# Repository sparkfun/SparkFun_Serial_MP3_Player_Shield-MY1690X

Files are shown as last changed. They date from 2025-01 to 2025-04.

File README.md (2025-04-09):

SparkFun Serial MP3 Player Shield - MY1690X
========================================

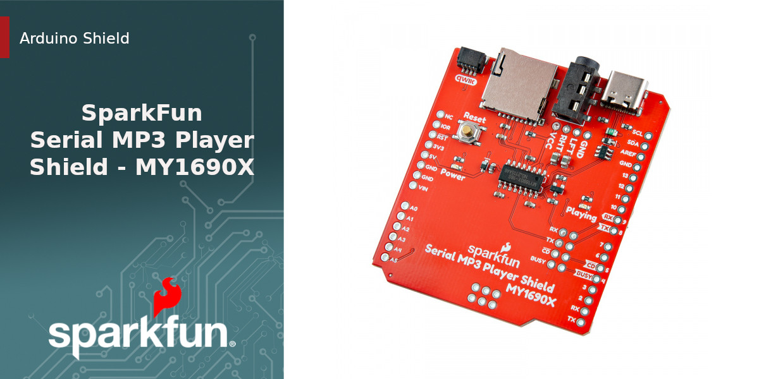
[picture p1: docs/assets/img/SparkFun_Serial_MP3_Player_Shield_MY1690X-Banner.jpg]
SparkFun Serial MP3 Player Shield - MY1690X (https://www.sparkfun.com/sparkfun-serial-mp3-player-shield-my1690x.html)


[*SparkFun Serial MP3 Player Shield - MY1690X (DEV-28021)*](https://www.sparkfun.com/sparkfun-serial-mp3-player-shield-my1690x.html)

The SparkFun Serial MP3 Player Shield - MY1690X is an R3 Arduino shield built around the MY1690X audio decoder IC. The MY1691X supports both .WAV and .MP3 audio files stored on a connected microSD card with up to 32GB capacity and formatted to FAT16 or FAT32. The MY1690X communicates over serial UART so we designed this shield to allow users to control the MY1690X while mounted on a compatible Arduino development board with an R4 footprint. 

Repository Contents
-------------------

* **.github/workflows** - YAML files used for GitHub Actions and GitHub Pages/mkdocs
* **/Hardware** - KiCad design files (.kicad_pcb, .kicad_sch, .kicad_pro)
  * **/Production** - Production panel files (.kicad_pcb)
* **/docs** - Online documentation files
  * **/assets** - Folder containing all the file assets used for product documentation
    * **/board_files** - Copy of design files used for product documentation
    * **/component_documentation** - Datasheets and manuals for hardware components
    * **/img** - Images for product documentation
  * **/github** - Files stating how to contribute and filing issues used for product documentation
  * **/javascript** - Folder containing custom javascript used for product documentation
  * **/stylesheet** - Folder containing CSS files used for product documentation
* **/overrides** - Customization files used for product documentation
  * **/.icons** - Icons used for GitHub used for product documentation
  * **./partials** - Used for product documentation

Documentation
--------------

* **[Arduino Library](https://github.com/sparkfun/SparkFun_MY1690_MP3_Decoder_Arduino_Library/)** - Arduino Library for the SparkFun Serial MP3 Player Shield - MY1690X.
* **[Hookup Guide](https://docs.sparkfun.com/SparkFun_Serial_MP3_Player_Shield-MY1690X)** - Basic hookup guide for the SparkFun Serial MP3 Player Shield - MY1690X.

Product Versions
----------------
* [DEV-28021](https://www.sparkfun.com/sparkfun-serial-mp3-player-shield-my1690x.html) - v1.0

Version History
---------------
* v1.0 - Initial release

License Information
-------------------

This product is _**open source**_!

Please review the LICENSE.md file for license information.

If you have any questions or concerns on licensing, please contact technical support on our [SparkFun forums](https://community.sparkfun.com/c/community/general-chit-chat/37).

Distributed as-is; no warranty is given.

- Your friends at SparkFun.

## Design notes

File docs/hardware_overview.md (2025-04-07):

Let's take a closer look at the SparkFun Serial MP3 Player Shield - MY1690X and the hardware present on the board. The photo below highlights the major components on this shield that we'll cover in more detail in this section:

<center>
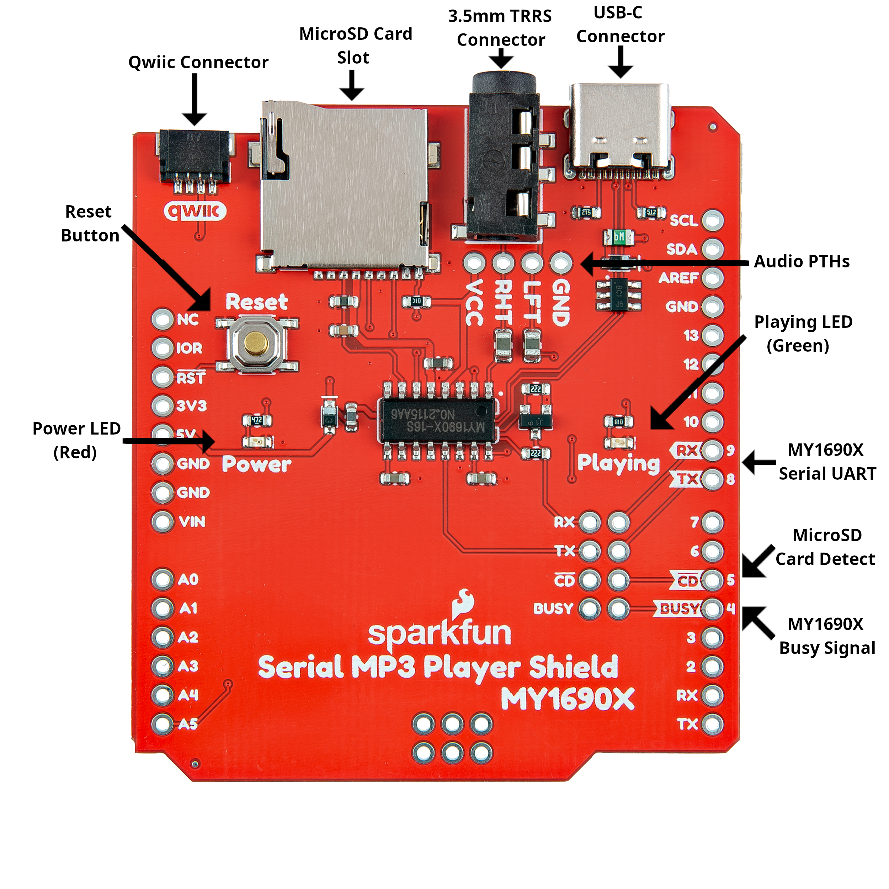
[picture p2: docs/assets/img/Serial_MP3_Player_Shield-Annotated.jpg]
Annotated photo of the MP3 Player Shield

</center>

## MY1690X MP3 Decoder IC

The MY1690X is an MP3 decoder IC that works with both MP3 and WAV audio files stored on a connected &micro;SD card. The MY1690X can function both as a removable USB drive when connected over USB to load, view or edit files on the SD card. The IC operates over a serial-UART interface at 3.3V TTL using a command set to control audio playback (Play, Pause, Next, etc.), volume and equalizer settings and query statuses (SD card contents, track name/length, etc.). It supports audio files with sampling rates between 8 and 48k with bit rates between 8 and 320Kbps.

## Connectors

The Serial MP3 Player Shield has three connectors. A USB-C connector, Qwiic connector and 3.5mm TRRS connector.

### USB-C

The USB-C connector on the shield connects directly to the MY1690X to mount it as a removable USB drive when a microSD card is inserted and the board is plugged into a computer. This allows you to directly add and remove audio files to a connected microSD card. This works great for small audio files but in our testing we found the transfer speed is quite slow and can take several minutes to upload larger audio files. We recommend uploading large files using a USB SD card reader or directly connecting your SD card to your computer.

When connected over USB-C (and with a microSD card plugged in) the MY1690X will stay in USB drive "mode" until a power cycle. The MY1690X does not have a Reset line so either unplug the board or press the RESET button on the shield to cycle power.

### Qwiic

The Qwiic connector on the shield lets you easily add other Qwiic devices to the board. It connects to 3.3V, Ground and both the dedicated SDA/SCL pins as well as A4 (SDA) and A5 (SCL).

### 3.5MM TRRS

The shield routes the audio output from the MY1690X to a 3.5MM TRRS audio connector as well as four 0.1"-spaced through hole pins. This allows you to easily plug in a pair of headphones directly to the shield or solder an alternate audio output. Note, the MY1690X can easily output audio for small headphones but you'll need an external amplifier on the audio output to drive larger speakers.

## MicroSD Card Slot

The shield's microSD card slot works with most standard SD cards that have up to 32GB storage space and formatted to FAT16 or FAT32. The MY1690X requires specific naming of files and folders stored on the card. Read on to the MicroSD Card Setup section of this guide for detailed information on naming conventions.

## Pinout

The Serial MP3 Player Shield matches the R4 footprint and has passthroughs for all of the pins on R4 development boards. The shield connects to the following pins on a connected Arduino dev board:

* D4 - MY1690X Busy Signal
* D5 - MY1690X Card Detect
* D8 - MY1690X TX Signal
* D9 - MY1690X RX Signal
* A4 - Qwiic SDA
* A5 - Qwiic SCL

The shield also has a 2x4 set of PTH pins near the center of the board to allow for routing the serial UART pins (RX/TX), Card Detect (CD) and Busy pins to alternate pins on a connected development board if necessary.

## LEDs

The Serial MP3 Player Shield has two LEDs labeled **PWR** and **BUSY**. The red **PWR** LED indicates whenever the board is powered. The green **BUSY** LED indicates whenever the MY1690X is playing audio.

## Reset Button

The Reset button on the shield is routed to a connected development board's reset pin to be used to reset the development board it's mounted on.

## Solder Jumpers

The shield has seven solder jumpers labeled **MIC**, **BUSY**, **PWR**, **RX**, **TX**, **CD** and **BUSY** (the two BUSY jumpers have different functions). The list below outlines each jumper's label, function, default state and any notes on how they work.

* **MIC** - The MIC jumper connects the Sleeve pin on the TRRS connector to Ground and is CLOSED by default. Open the jumper to disable this pull-down for headphones that have a built-in microphone.
* **BUSY** - The first BUSY jumper completes the Busy LED circuit and is CLOSED by default. Open the jumper to disable the Busy LED.
* **PWR** - The PWR jumper completes the Power LED circuit and is CLOSED by default. Open the jumper to disable the Power LED.
* **RX** - The RX jumper connects the MY1690X's RX pin to D9 and is CLOSED by default. Open the jumper to isolate the MY1690X's RX signal from D9 if you need to route it to another pin.
* **TX** - The TX jumper connects the MY1690X's TX pin to D9 and is CLOSED by default. Open the jumper to isolate the TX signal from D8 if you need to route it to another pin.
* **CD** - The CD jumper connects the MY1690X's Card Detect (CD) to D4 and is CLOSED by default. Open the jumper to disconnect the CD pin from D4 if you need to connect it to another pin.
* **BUSY** - The second BUSY jumper connects the MY1690X's Busy pin to D5 and is CLOSED by default. Open the jumper to disconnect the Busy pin from D5 if you need to connect it to another pin.

## Board Dimensions

The Serial MP3 Player Shield - MY1690X fits the R4 footprint and measures 2.35" x 2.1" (59.69mm x 53.34mm).

<center>
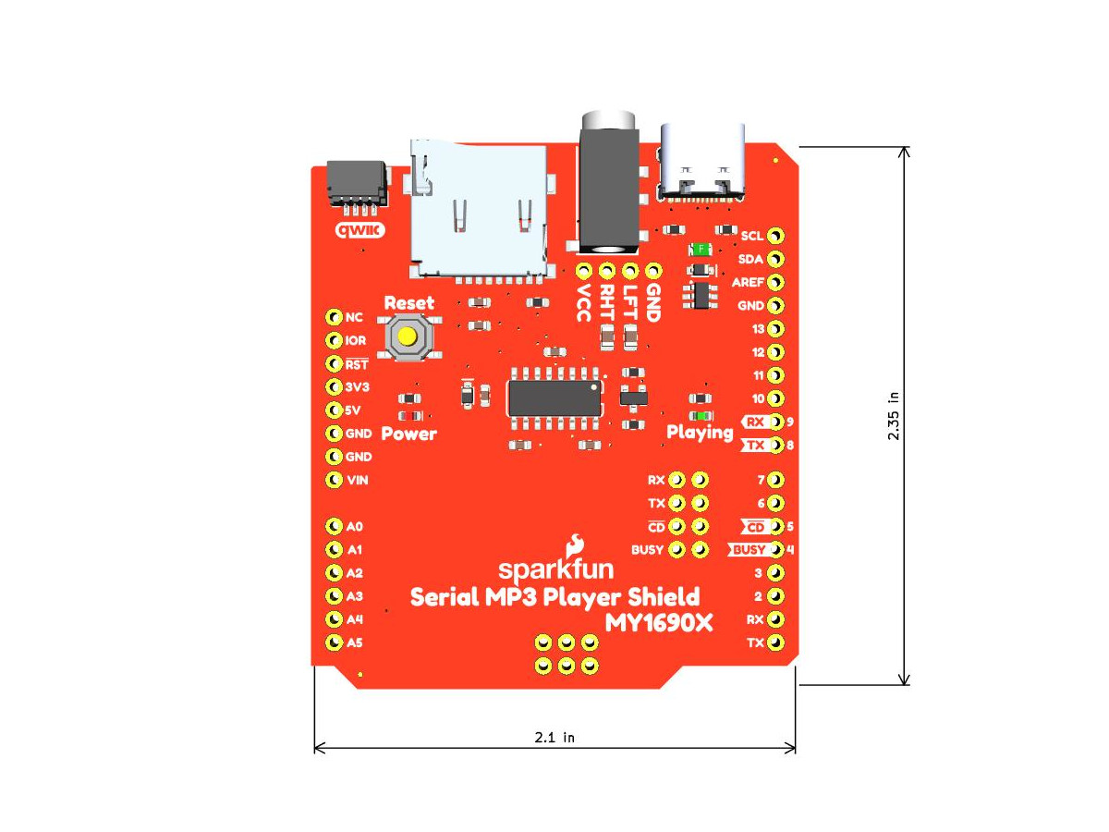
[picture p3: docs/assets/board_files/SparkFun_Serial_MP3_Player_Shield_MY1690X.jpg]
Board Dimensions

</center>

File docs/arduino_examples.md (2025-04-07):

The SparkFun MY1690 MP3 Decoder Arduino library includes three examples to demonstrate how to use the library. Let's take a closer look at these examples.

## Example 1 - Play File

The first example plays the first audio track stored on a connected SD card once through and stops. In Arduino, open the example by navigating to **File** > **Examples** > **SparkFun MY1690X MP3 Decoder Arduino Library** > **Example1_PlayFile**. Select the **Board** and **Port** and click "Upload". Once upload finishes, the code will automatically start by playing the first track stored on the SD card so make sure to have headphones/speakers connected to hear the audio as it does not repeat. You can push the Reset button on the shield to reset the board and start the code over to hear the track play again.

The code does have some serial printouts to help troubleshoot if the code hangs on attempting to initialize the MY1690X or when checking the SD card for audio tracks. If you have any issues with playback, open the [serial monitor](https://docs.arduino.cc/software/ide-v2/tutorials/ide-v2-serial-monitor/) with the baud set to **115200** to view the serial prints from the code.

## Example 2 - Kitchen Sink

The second example demonstrates how to use all of the available commands on the MY1690X to control and manipulate audio tracks through a serial menu. Open the example by navigating to **File** > **Examples** > **SparkFun MY1690X MP3 Decoder Arduino Library** > **Example2_KitchenSink**. Select the **Board** and **Port** and click "Upload". After the code finishes uploading, open the serial monitor with the baud set to **115200** and you should see a menu like the screenshot below:

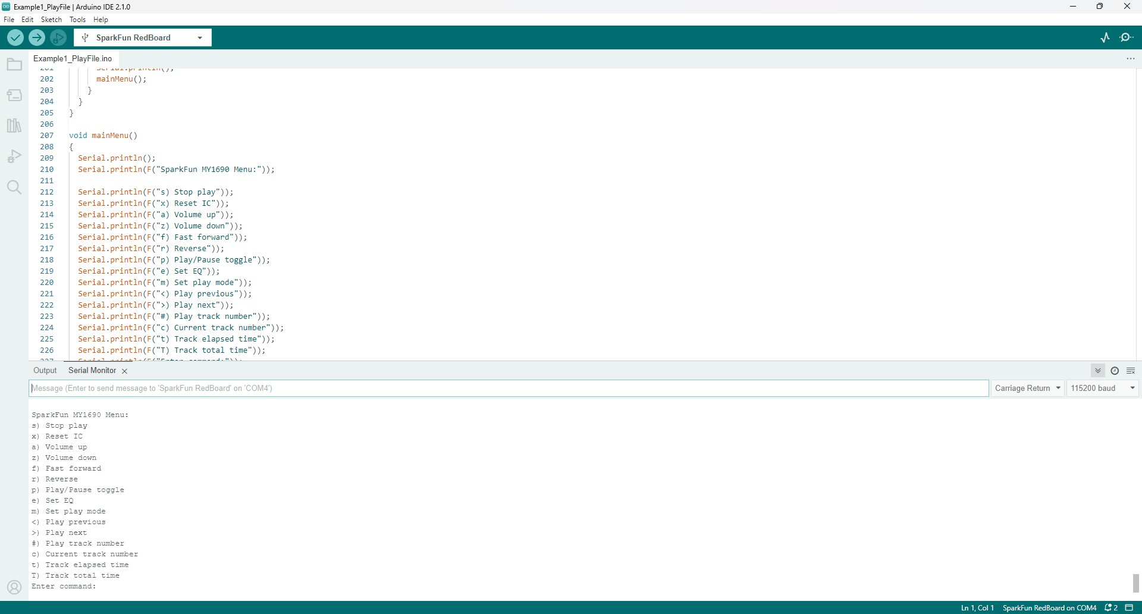
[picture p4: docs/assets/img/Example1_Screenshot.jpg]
Screenshot of example 2 serial menu


The MY1690 Menu has options for all the available playback and settings commands for the MY1690X. Some like "Play" or "Reverse" are straightforward and perform the expected action. The options for setting the equalizer (Set EQ) and play mode (Set Play Mode) cycle through the available options for these settings and print out the matching number. The Equalizer and Play modes are listed below and can be found in the instruction list in section 6.1 of the [MY1690X datasheet](./assets/component_documentation/MY1690X‑16S%20MP3%20Decoder%20IC%20User%20Manual.pdf):

**Equalizer Modes**

* 0 - None
* 1 - Pop
* 2 - Rock
* 3 - Jazz
* 4 - Classic
* 5 - Bass

**Play Modes**

* 0 - Full
* 1 - Folder
* 2 - Single
* 3 - Random
* 4 - No Loop

## Example 3 - Kitchen Sink ESP32

Example 3 - Kitchen Sink ESP32 is nearly identical to Example 2 but is modified to work with ESP32-based development boards like the [SparkFun IoT RedBoard - ESP32](https://www.sparkfun.com/sparkfun-iot-redboard-esp32-development-board.html). Open the example by navigating to **File** > **Examples** > **SparkFun MY1690X MP3 Decoder Arduino Library** > **Example2_KitchenSink**. Select the **Board** (SparkFun IoT RedBoard - ESP32 or other ESP32 dev board) and **Port** and click "Upload". After the code finishes uploading, open the serial monitor with the baud set to **115200** to view the same serial menu as pictured above.

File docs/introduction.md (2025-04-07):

Banner photo for Serial MP3 Player Shield

The SparkFun Serial MP3 Player Shield - MY1690X is an R3 Arduino shield built around the MY1690X audio decoder IC. The MY1691X supports both .WAV and .MP3 audio files stored on a connected microSD card with up to 32GB capacity and formatted to FAT16 or FAT32. The MY1690X communicates over serial UART so we designed this shield to allow users to control the MY1690X while mounted on a compatible Arduino development board with an R4 footprint. 

You'll need the following items to follow along with this tutorial:

* [SparkFun Serial MP3 Player Shield - MY1690X](https://www.sparkfun.com/sparkfun-serial-mp3-player-shield-my1690x.html)
* [SparkFun RedBoard Plus](https://www.sparkfun.com/sparkfun-redboard-plus.html) or other R4 Arduino dev board
* [Arduino Stackable Header Kit](https://www.sparkfun.com/arduino-stackable-header-kit-r3.html) or other header type
* [USB-C Cable](https://www.sparkfun.com/reversible-usb-a-to-c-cable-0-8m.html)

This shield does require soldering to work properly so you'll need a soldering iron and soldering accessories to complete the shield assembly.

## Topics Covered

This document contains three main sections: **Quickstart Guide**, **Hardware** and **Software**. 

The Quickstart Guide assumes a working knowledge of how to assemble and use a shield with a compatible Arduino development board along with the required software to program them for your project's needs. It covers a quick assembly and then jumps right into getting the necessary software packages installed to start uploading code in just a few short minutes.

The Hardware pages cover a hardware overview that provides a detailed overview of the Serial MP3 Player Shield - MY1690X covering all the major components on the board in detail as well as a hardware assembly page which goes over the steps required to assemble and use the shield with a compatible Arudino board.

The Software pages give instructions on installing the SparkFun MY1690 MP3 Decoder Arduino and using the examples included in it.

## Resources and Documentation

You'll find the board design files (KiCad files & schematic), relevant documentation (datasheets, white papers, etc.) and other helpful links in the **Resources**. Lastly, the **Support** section includes a Troubleshooting page that includes any helpful tips specific to this board as well as information on how to receive technical support from SparkFun.

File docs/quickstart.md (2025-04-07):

In this Quick Start guide we'll assemble the SparkFun Serial MP3 Player Shield - MY1690X, mount it to a SparkFun RedBoard Plus and use the SparkFun MY1690X MP3 Decoder Arduino Library to play audio stored on a connected microSD card. 

If you're not familiar with using Arduino shields and development boards or the Arduino IDE, refer to the [Hardware](./hardware_overview.md) & [Software](./arduino_setup.md) sections for a detailed overview of the board along with instructions on assembling the shield, installing and using the SparkFun MY1690X MP3 Decoder Arduino Library.

## Shield Assembly & Mounting

Start by soldering your selected headers to the shield so it can mount on to a compatible R4 development board. We opted for male headers here but you can use stackable headers if you'd like to stack another shield on top of this to add more functionality to your audio project:

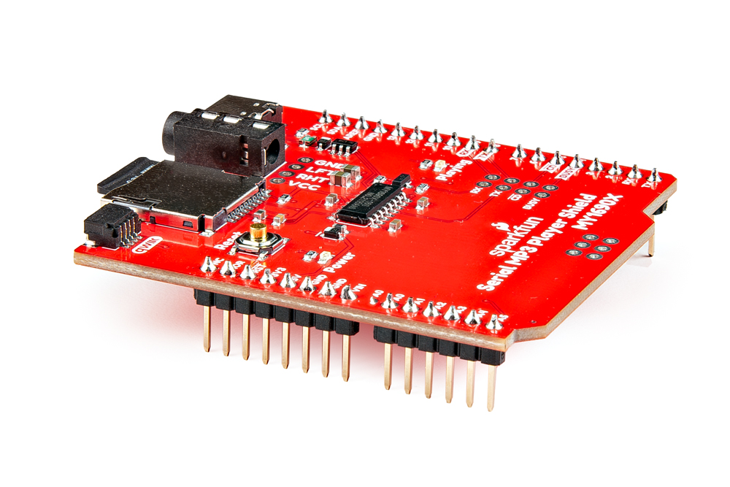
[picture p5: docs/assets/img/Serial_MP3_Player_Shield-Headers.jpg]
Photo showing headers soldered to MP3 Player Shield


After soldering, plug the shield into your development board and connect the development board to your computer with a USB cable:

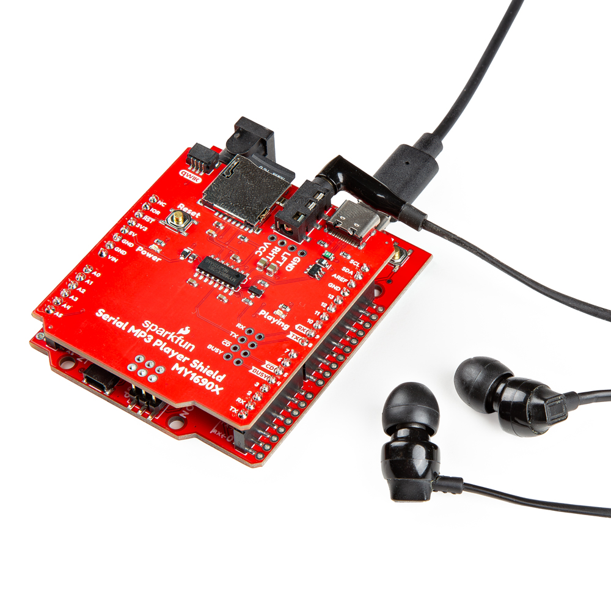
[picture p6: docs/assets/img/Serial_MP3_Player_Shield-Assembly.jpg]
Photo of completed assembly


You'll also want to plug in a pair of headphones to the 3.5mm audio jack on the shield. The MY1690X can drive a pair of headphones on its own but requires an external amplifier to drive larger speakers.

## Prepare SD Card

The MY1690X works with standard SD cards up to 32GB capacity and formatted to either FAT16 or FAT32. Users can upload files to an SD card mounted on the shield by plugging it into a computer over USB-C or can load them directly onto the SD card using a USB Card Reader or the SD card slot on their computer. Files and folders on a connected SD card should match the following naming conventions:

* .MP3/.WAV files in the root directory must begin with a four digit number (eg. 000#) starting at 0001 and can have characters following the numbers
* Folders should begin with a two digit number (eg. 0#) starting at 01 and can have characters following the numbers.
* .MP3/.WAV files stored inside folders must begin with three digits (eg. 00#) starting at 001 and can have characters following the numbers.

Make sure to load the audio tracks onto the SD card and then proceed to the Arduino Example.

## Arduino Example

With the shield soldered and mounted on your Arduino dev board, let's upload Example 2 - Kitchen Sink to the board to start playing and controlling audio. This example will start playing the first track once it's uploaded and also includes a serial menu to access all of the UART commands using simple text commands. Follow the steps below to upload the example.

* Open the [Arduino IDE](https://docs.arduino.cc/software/ide-v2/tutorials/getting-started-ide-v2/).
* Open the [Library Manager](https://docs.arduino.cc/software/ide-v2/tutorials/ide-v2-installing-a-library/) tool, search for "SparkFun MY1690X MP3 Decoder" and install the latest version 
* Open "Example 2 - Kitchen Sink".
* Select your Board (SparkFun RedBoard or other R4 board) and Port and click "Upload".
* After the code compiles and finishes uploading, open the [serial monitor](https://docs.arduino.cc/software/ide-v2/tutorials/ide-v2-serial-monitor/) with the baud set to **115200**.
* The code prints out a menu of available commands to control the MY1690X's playback. Type in the command you'd like to do and hit Enter or click Send.
* Have fun playing around controlling track playback, volume and other features.

Screenshot of example 1 in Arduino

### Code to Note

* Serial Setup
``` c++
#include "SoftwareSerial.h"
SoftwareSerial serialMP3(8, 9); //RX on Arduino connected to TX on MY1690's, TX on Arduino connected to the MY1690's RX pin

//For boards that have multiple hardware serial ports
//HardwareSerial serialMP3(2); //Create serial port on ESP32: TX on 17, RX on 16
```
The code has options for both Software Serial and Hardware Serial depending on your dev board. The code defaults to use pins D8 and D9 for software serial

* MY1690X & Track Checks

```c++
if (myMP3.begin(serialMP3) == false) // Beginning the MP3 player requires a serial port (either hardware or software)
  {
    Serial.println(F("Device not detected. Check wiring. Freezing."));
    while (1);
  }

  int songCount = myMP3.getSongCount();
  if (songCount == 0)
  {
    Serial.println(F("Oh no! No songs found. Make sure the SD card is inserted and there are MP3s on it. Freezing."));
    while (1);
  }
```
On setup, the code checks to detect the MY1690X over serial and also checks to make sure the SD card has audio tracks 

* Get Track Numbers, MY1690 Version and Play First Track
```c++
  Serial.print(F("Number of tracks on SD card: "));
  Serial.println(songCount);

  Serial.print(F("MY1690 Version: "));
  Serial.println(myMP3.getVersion());

  myMP3.play(); //Will play the lowest numbered song in the folder
```

The example will print out the number of tracks detected on the SD card, the MY1690 version and then will play the lowest numbered song on the card. Note, it takes ~30ms for a track to start playing so the code waits 50ms before requesting play status.

* MY1690X Menu Options

This menu shows the available commands to control playback. Type in the matching character in the serial monitor and hit Enter to send it. The Set EQ and Set play mode commands cycle through the available equalizer and play mode options. Refer to the Arduino Examples section of this guide or section 6.1 of the [datasheet](./assets/component_documentation/MY1690X‑16S%20MP3%20Decoder%20IC%20User%20Manual.pdf) for more information.

```c++
void mainMenu()
{
  Serial.println();
  Serial.println(F("SparkFun MY1690 Menu:"));

  Serial.println(F("s) Stop play"));
  Serial.println(F("x) Reset IC"));
  Serial.println(F("a) Volume up"));
  Serial.println(F("z) Volume down"));
  Serial.println(F("f) Fast forward"));
  Serial.println(F("r) Reverse"));
  Serial.println(F("p) Play/Pause toggle"));
  Serial.println(F("e) Set EQ"));
  Serial.println(F("m) Set play mode"));
  Serial.println(F("<) Play previous"));
  Serial.println(F(">) Play next"));
  Serial.println(F("#) Play track number"));
  Serial.println(F("c) Current track number"));
  Serial.println(F("t) Track elapsed time"));
  Serial.println(F("T) Track total time"));
  Serial.println(F("Enter command:"));
}
```

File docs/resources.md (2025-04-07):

Refer to the resources below for more information on the SparkFun Serial MP3 Player Shield - MY1690X.

* [Schematic](./assets/board_files/SparkFun_Serial_MP3_Player_Shield_MY1690X.pdf)
* [KiCad Files](./assets/board_files/SparkFun_Serial_MP3_Player_Shield_MY1690X.zip)
* [Board Dimensions](./assets/board_files/SparkFun_Serial_MP3_Player_Shield_MY1690X.jpg)
* [MY1690X Datasheet](./assets/component_documentation/MY1690X‑16S%20MP3%20Decoder%20IC%20User%20Manual.pdf)
* [SparkFun MP3 Decoder Arduino Library](https://github.com/sparkfun/SparkFun_MY1690_MP3_Decoder_Arduino_Library)
* [GitHub Repository](https://github.com/sparkfun/SparkFun_Serial_MP3_Player_Shield-MY1690X)

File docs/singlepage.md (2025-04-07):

---
hide:
  - navigation
  - toc
icon: fontawesome/solid/scroll
---

# Introduction
--8<-- "./docs/introduction.md"

# Quickstart Guide
--8<-- "./docs/quickstart.md"

# Hardware Overview
--8<-- "./docs/hardware_overview.md"

# Hardware Hookup
--8<-- "./docs/hardware_assembly.md"

# MicroSD Card Setup
--8<-- "./docs/microsd.md

# Setting Up Arduino
--8<-- "./docs/arduino_setup.md"

# Arduino Examples
--8<-- "./docs/arduino_examples.md"

# Troubleshooting
--8<-- "./docs/troubleshooting.md"

# Resources
--8<-- "./docs/resources.md"

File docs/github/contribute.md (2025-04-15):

# Contribute: Make an Augmentation!
Spot an improvement opportunity? Feel free to contribute to our open-source design and documentation. 

## :material-file-document-multiple:&nbsp;Improve our Documentation
All of this documentation can be modified by you! Please help us make it better.

* These pages are contained in the [`docs` folder](https://github.com/sparkfun/SparkFun_Serial_MP3_Player_Shield-MY1690X/tree/main/docs) of the [SparkFun Serial MP3 Player Shield - MY1690X repository](https://github.com/sparkfun/SparkFun_Serial_MP3_Player_Shield-MY1690X).

<!-- ### :material-source-pull:&nbsp;Submit a Correction -->
### Submit a Correction

1. With a GitHub account, [fork this repository](https://github.com/sparkfun/SparkFun_Serial_MP3_Player_Shield-MY1690X/fork).
2. Add your corrections or improvements to the markdown file.
3. File a pull request with your changes, and enjoy making the ~~words~~ ~~worlds~~ world a better place.
	* Once received, the documentation specialist will automatically be notified.
	* We will review your suggested improvements to make sure they are correct and fit within our documentation standards.

## :material-cog:&nbsp;Improve our Hardware Design
All of our designs are open-source! Please help us make it better.

* Our board design files are contained in the [`Hardware` folder](https://github.com/sparkfun/SparkFun_Serial_MP3_Player_Shield-MY1690X/tree/main/Hardware) of the [SparkFun Serial MP3 Player Shield - MY1690X repository](https://github.com/sparkfun/SparkFun_Serial_MP3_Player_Shield-MY1690X).

<!-- ### :material-source-pull:&nbsp;Submit a Design Enhancement -->
### Submit a Design Enhancement

1. With a GitHub account, [fork this repository](https://github.com/sparkfun/SparkFun_Serial_MP3_Player_Shield-MY1690X/fork).
2. Add your design augmentation(s)
3. File a pull request with your changes, and enjoy making the ~~words~~ ~~worlds~~ world a better place.
	1. Once received, the engineer in charge of the original design will automatically be notified.
	2. We will review your suggested improvement(s) to verify that they are within our board design standards and meet our product design requirements.
	3. If approved, we will flag these changes for our next board revision. Congrats! 🍻

		!!! info
			Even if your suggestion is accepted, these changes may not be immediately available for purchase. We may have to cycle through our current product inventory first.

## Contributors&nbsp;:clap:
Let's provide some recognition to the contributors for this project!

GitHub Contributors Image
<br>


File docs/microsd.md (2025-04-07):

The MY1690X works with standard microSD cards up to 32GB capacity and formatted to either FAT16 or FAT32.

## Format &micro;SD Card

If you're using a brand new SD card, you may not need to format it though it may come with pre-installed files that could cause performance issues. The Quick Format option in Windows is the usually the simplest method to properly format the &micro;SD card. Otherwise there are many free software options for formatting SD cards available online.

## Upload Audio Files

The MY1690X supports both .MP3 and .WAV audio files and acts as a removable USB drive while plugged in over USB-C to directly add audio files to a connected &micro;SD card. In our testing, we found the MY1690X transfer speed is somewhat limited and can take several minutes to upload larger files. If you're moving a large number or large files to use on the Serial MP3 Shield you may want to use a USB SD card reader or plug your SD card into the matching slot on your computer. 

### File & Folder Naming

The MY1690X requires specific naming conventions for files and folders stored on the SD card. Audio files stored in the root directory must begin with a four digit number (000#) starting at 0001 and can have characters following the numbers. Folders should be named with two digits at the start (0#) and then can have descriptive characters following the numbers. Files stored in these folders must be named starting with three digits (00#) and can have characters after the numbers. Refer to section 6.3 in the [datasheet](./assets/component_documentation/MY1690X‑16S%20MP3%20Decoder%20IC%20User%20Manual.pdf) for more information on naming requirements.

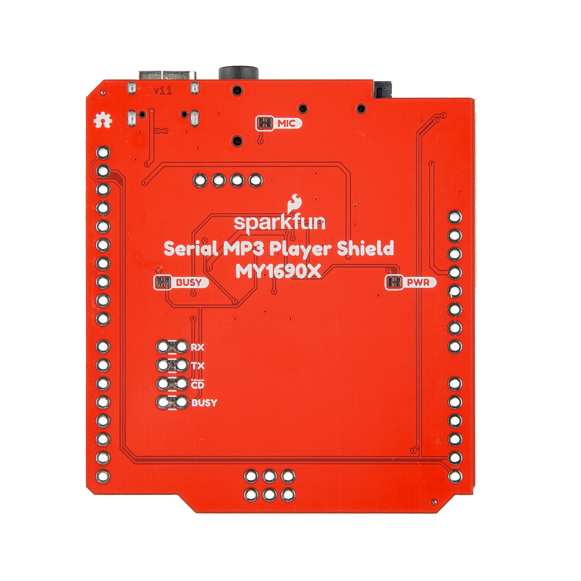
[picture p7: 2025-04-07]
docs/assets/img/28021-Serial-MP3-Player-Shield-Back-high-res.jpg

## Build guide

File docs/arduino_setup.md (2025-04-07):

!!! arduino
    This example assumes you are using the latest version of the Arduino IDE on your desktop. If this is your first time using Arduino IDE, library, or board add-on, please review the following tutorials.

    - [Installing the Arduino IDE](https://learn.sparkfun.com/tutorials/installing-arduino-ide)
    - [Installing an Arduino Library](https://learn.sparkfun.com/tutorials/installing-an-arduino-library)
    - [Installing Board Definitions in the Arduino IDE](https://learn.sparkfun.com/tutorials/installing-board-definitions-in-the-arduino-ide)

## Installing the SparkFun MY1690X MP3 Decoder Arduino Library

The SparkFun MY1690X MP3 Decoder Arduino Library parses the MY1690X's full command set into a user-friendly menu controlled using a serial terminal. Install the library using the Arduino Library Manager tool by searching for "SparkFun MY1690X" and install the latest version. If you'd prefer to manually install the library, you can download it from the [GitHub Repository](https://github.com/sparkfun/SparkFun_MY1690_MP3_Decoder_Arduino_Library) or you can download a ZIP of the repository [here](https://github.com/sparkfun/SparkFun_MY1690_MP3_Decoder_Arduino_Library/archive/refs/heads/main.zip).

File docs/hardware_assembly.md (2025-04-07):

??? note "New to soldering?"
	If you have never soldered before or need a quick refresher, check out our [How to Solder: Through-Hole Soldering](https://learn.sparkfun.com/tutorials/how-to-solder-through-hole-soldering) guide.
	<p align="center">
		<a href="https://learn.sparkfun.com/tutorials/5">
		Tutorial's thumbnail<br>
        How to Solder: Through-Hole Soldering</a>
	</p>

Start by soldering your selected headers to the shield so it can mount on to a compatible R4 development board. We opted for male headers here but you can use stackable headers if you'd like to stack another shield on top of this to add more functionality to your audio project:

Photo showing headers soldered to MP3 Player Shield

After soldering, plug the shield into your development board, insert your microSD card and connect the development board to your computer with a USB cable:

Photo of completed assembly

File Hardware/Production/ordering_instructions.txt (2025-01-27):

Ordering Instructions:
Panel dimensions: 120.80 x 203.85 mm.
Solder Mask: Red
Silkscreen Color: White
Layers: 2
Finish: Lead-free HASL
Thickness: 1.6mm
Outer Copper Weight: 1oz
Minimum track width: 0.15mm (6.00mil)
Minimum via drill: 0.30mm (11.81mil)

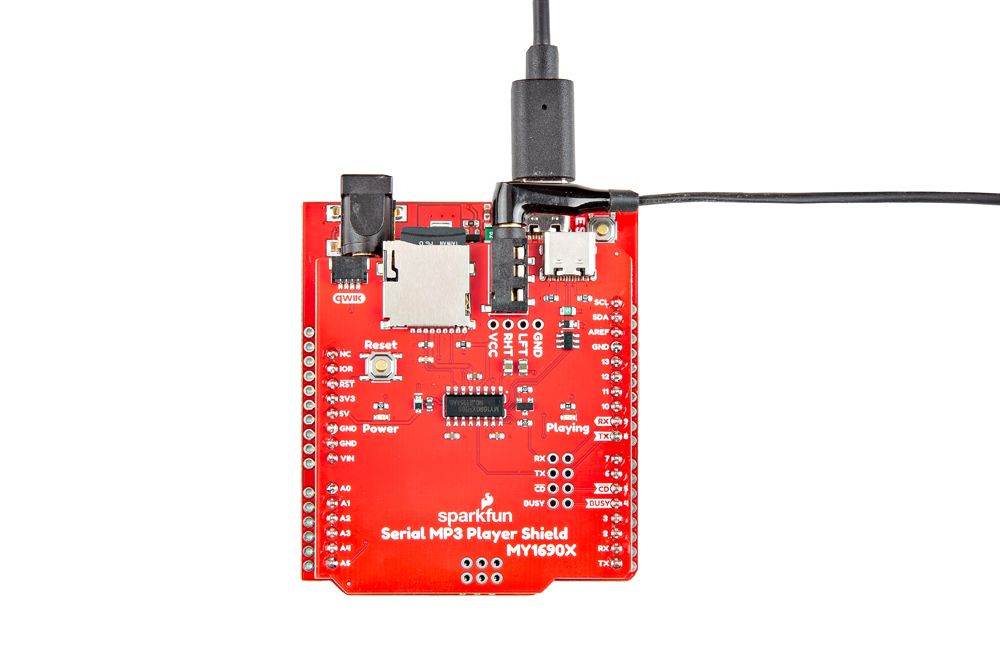
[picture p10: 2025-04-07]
docs/assets/img/Serial_MP3_Player_Shield-Assembly_Top.jpg

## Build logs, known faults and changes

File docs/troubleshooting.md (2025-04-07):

## Audio Track Naming

One of the most common issues we expect you to run into will revolve around track naming outlined in the MicroSD Card Setup section of this guide and section 6.3 of the [datasheet](./assets/component_documentation/MY1690X‑16S%20MP3%20Decoder%20IC%20User%20Manual.pdf).Remember that tracks and folders must start at 0001 (Track in root directory), 001 (Track in folder) and 01 (Folder). Any tracks and folders not explicitly following the naming convention will be ignored by the MY1690X.

## General Troubleshooting Help

!!! note
    <span class="glyphicon glyphicon-question-sign" aria-hidden="true"></span>
        <strong> Not working as expected and need help? </strong> <br /><br />

    If you need technical assistance and more information on a product that is not working as you expected, we recommend heading on over to the <a href="https://www.sparkfun.com/technical_assistance">SparkFun Technical Assistance</a> page for some initial troubleshooting. <br /><br />

    <div style="text-align: center"><a href="https://www.sparkfun.com/technical_assistance" target="sfe_technical_assistance" class="md-button">SparkFun Technical Assistance Page</a></div>

    If you don't find what you need there, the <a href="https://community.sparkfun.com/">SparkFun Forums</a> are a great place to find and ask for help. If this is your first visit, you'll need to create a forum account to search product forums and post questions.<br /><br />

    <div style="text-align: center"><a href="https://community.sparkfun.com/" class="md-button md-button--primary">Log Into SparkFun Forums</a></div>

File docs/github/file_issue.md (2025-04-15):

# Did we make a mistake?

Spot something wrong? Please let us know. 

## Discrepancies in the Documentation

All of our documentation can be modified by you! Please help us make it better.

* The documentation files for these pages are contained in the [`docs` folder](https://github.com/sparkfun/SparkFun_Serial_MP3_Player_Shield-MY1690X/tree/main/docs) of the [SparkFun Serial MP3 Player Shield - MY1690X repository](https://github.com/sparkfun/SparkFun_Serial_MP3_Player_Shield-MY1690X).

### 🔍 Spot something wrong?

If a section of the documentation is incorrect, please [open an issue](https://github.com/sparkfun/SparkFun_Serial_MP3_Player_Shield-MY1690X/issues) and let us know.

### Do you have a suggested correction?

1. With a GitHub account, [fork this repository](https://github.com/sparkfun/SparkFun_Serial_MP3_Player_Shield-MY1690X/fork).
2. Add your correction(s) or improvement(s) to the markdown file(s)
3. File a pull request with your changes, and enjoy making the ~~words~~ ~~worlds~~ world a better place.
	* Once received, the documentation specialist will automatically be notified.
	* We will review your suggested improvement(s) to make sure they are correct and fit within our documentation standards.

## Problems in the Hardware Design

All of our designs are open-source! Please help us make it better.

* Our board design files are contained in the [`Hardware` folder](https://github.com/sparkfun/SparkFun_Serial_MP3_Player_Shield-MY1690X/tree/main/Hardware) of the [SparkFun Serial MP3 Player Shield - MY1690X repository](https://github.com/sparkfun/SparkFun_Serial_MP3_Player_Shield-MY1690X).

### Does something not make sense? 🤔

If part of the design is confusing, please [open an issue](https://github.com/sparkfun/SparkFun_Serial_MP3_Player_Shield-MY1690X/issues) and let us know.

### Did we forget to include an important function of the board? 🤦

If part of the board's functionality is missing, please [open an issue](https://github.com/sparkfun/SparkFun_Serial_MP3_Player_Shield-MY1690X/issues) and file a feature request.

!!! tip "Design Considerations"
	Please keep in mind that we may intentionally exclude certain functions of the board to meet our product design requirements.
	
	* *For example, our Qwiic Micro boards are intended to fit on a small board layout and only use I<sup>2</sup>C communication; therefore, we may not have the SPI and interrupt pins available for users.*

### Do you wish to contribute directly to improving the board design?

1. With a GitHub account, [fork this repository](https://github.com/sparkfun/SparkFun_Serial_MP3_Player_Shield-MY1690X/fork).
2. Add your design augmentation(s)
3. File a pull request with your changes, and enjoy making the ~~words~~ ~~worlds~~ world a better place.
	1. Once received, the engineer in charge of the original design will automatically be notified.
	2. We will review your suggested improvement(s) to verify that they are within our board design standards and meet our product design requirements.
	3. If approved, we will flag these changes for our next board revision. Congrats! 🍻

		!!! info
			Even if your suggestion is accepted, these changes may not be immediately available for purchase. We may have to cycle through our current product inventory first.

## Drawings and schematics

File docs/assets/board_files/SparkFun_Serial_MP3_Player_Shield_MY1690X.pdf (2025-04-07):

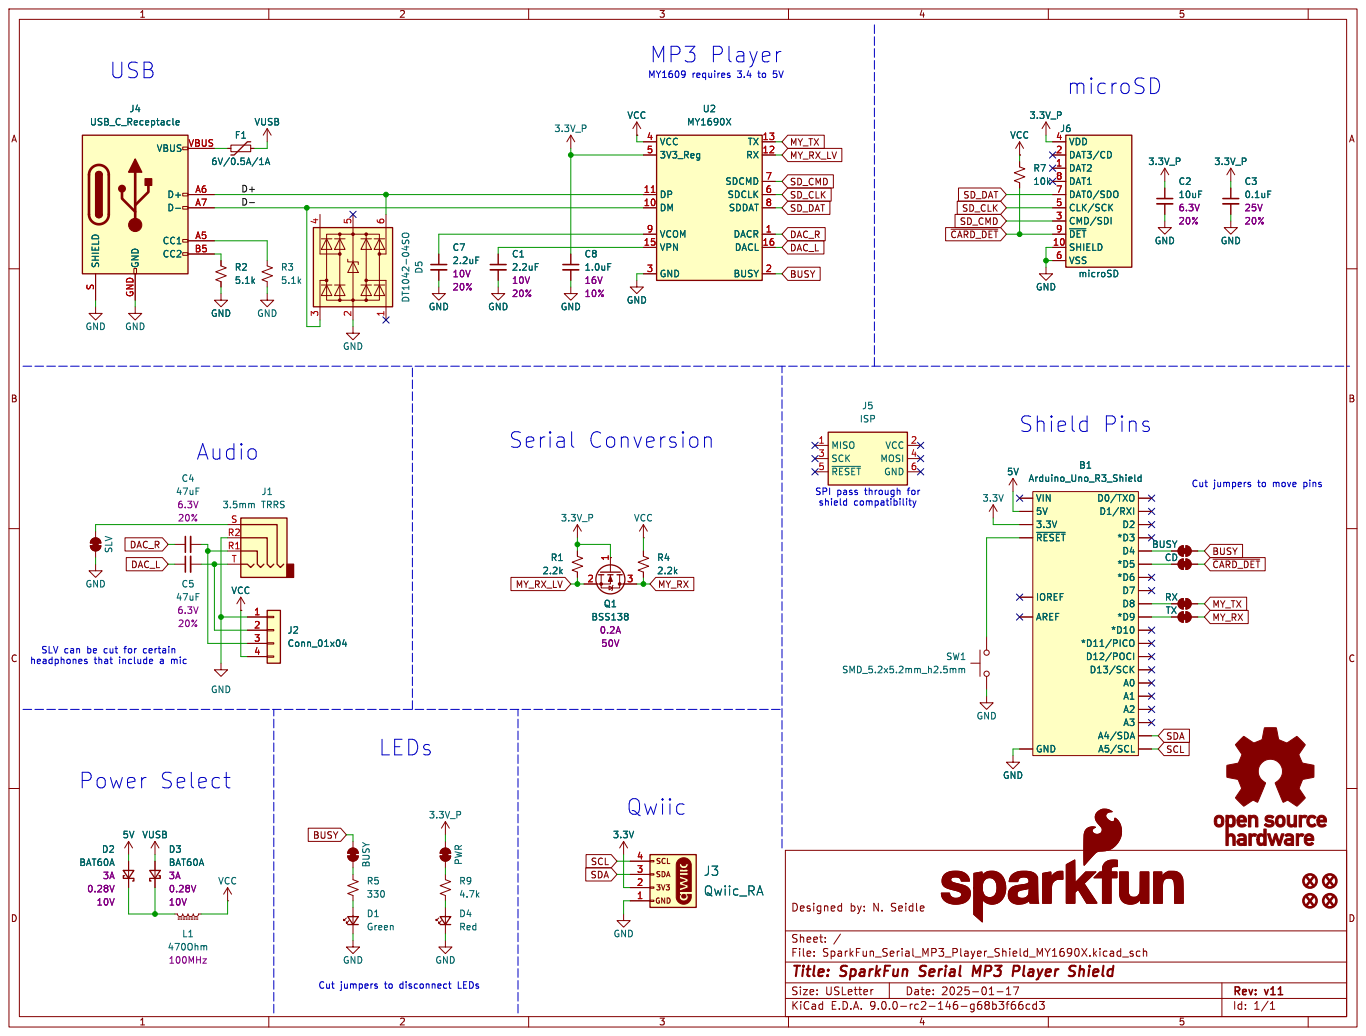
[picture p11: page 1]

VDD 4 DAT3/CD 2 DAT2 1 DAT1 8 DAT0/SDO 7 CLK/SCK 5 CMD/SDI 3 ~{DET} 9 SHIELD 10 VSS 6 VCC

SLV can be cut for certain

Id: 1/1 Title: SparkFun Serial MP3 Player Shield

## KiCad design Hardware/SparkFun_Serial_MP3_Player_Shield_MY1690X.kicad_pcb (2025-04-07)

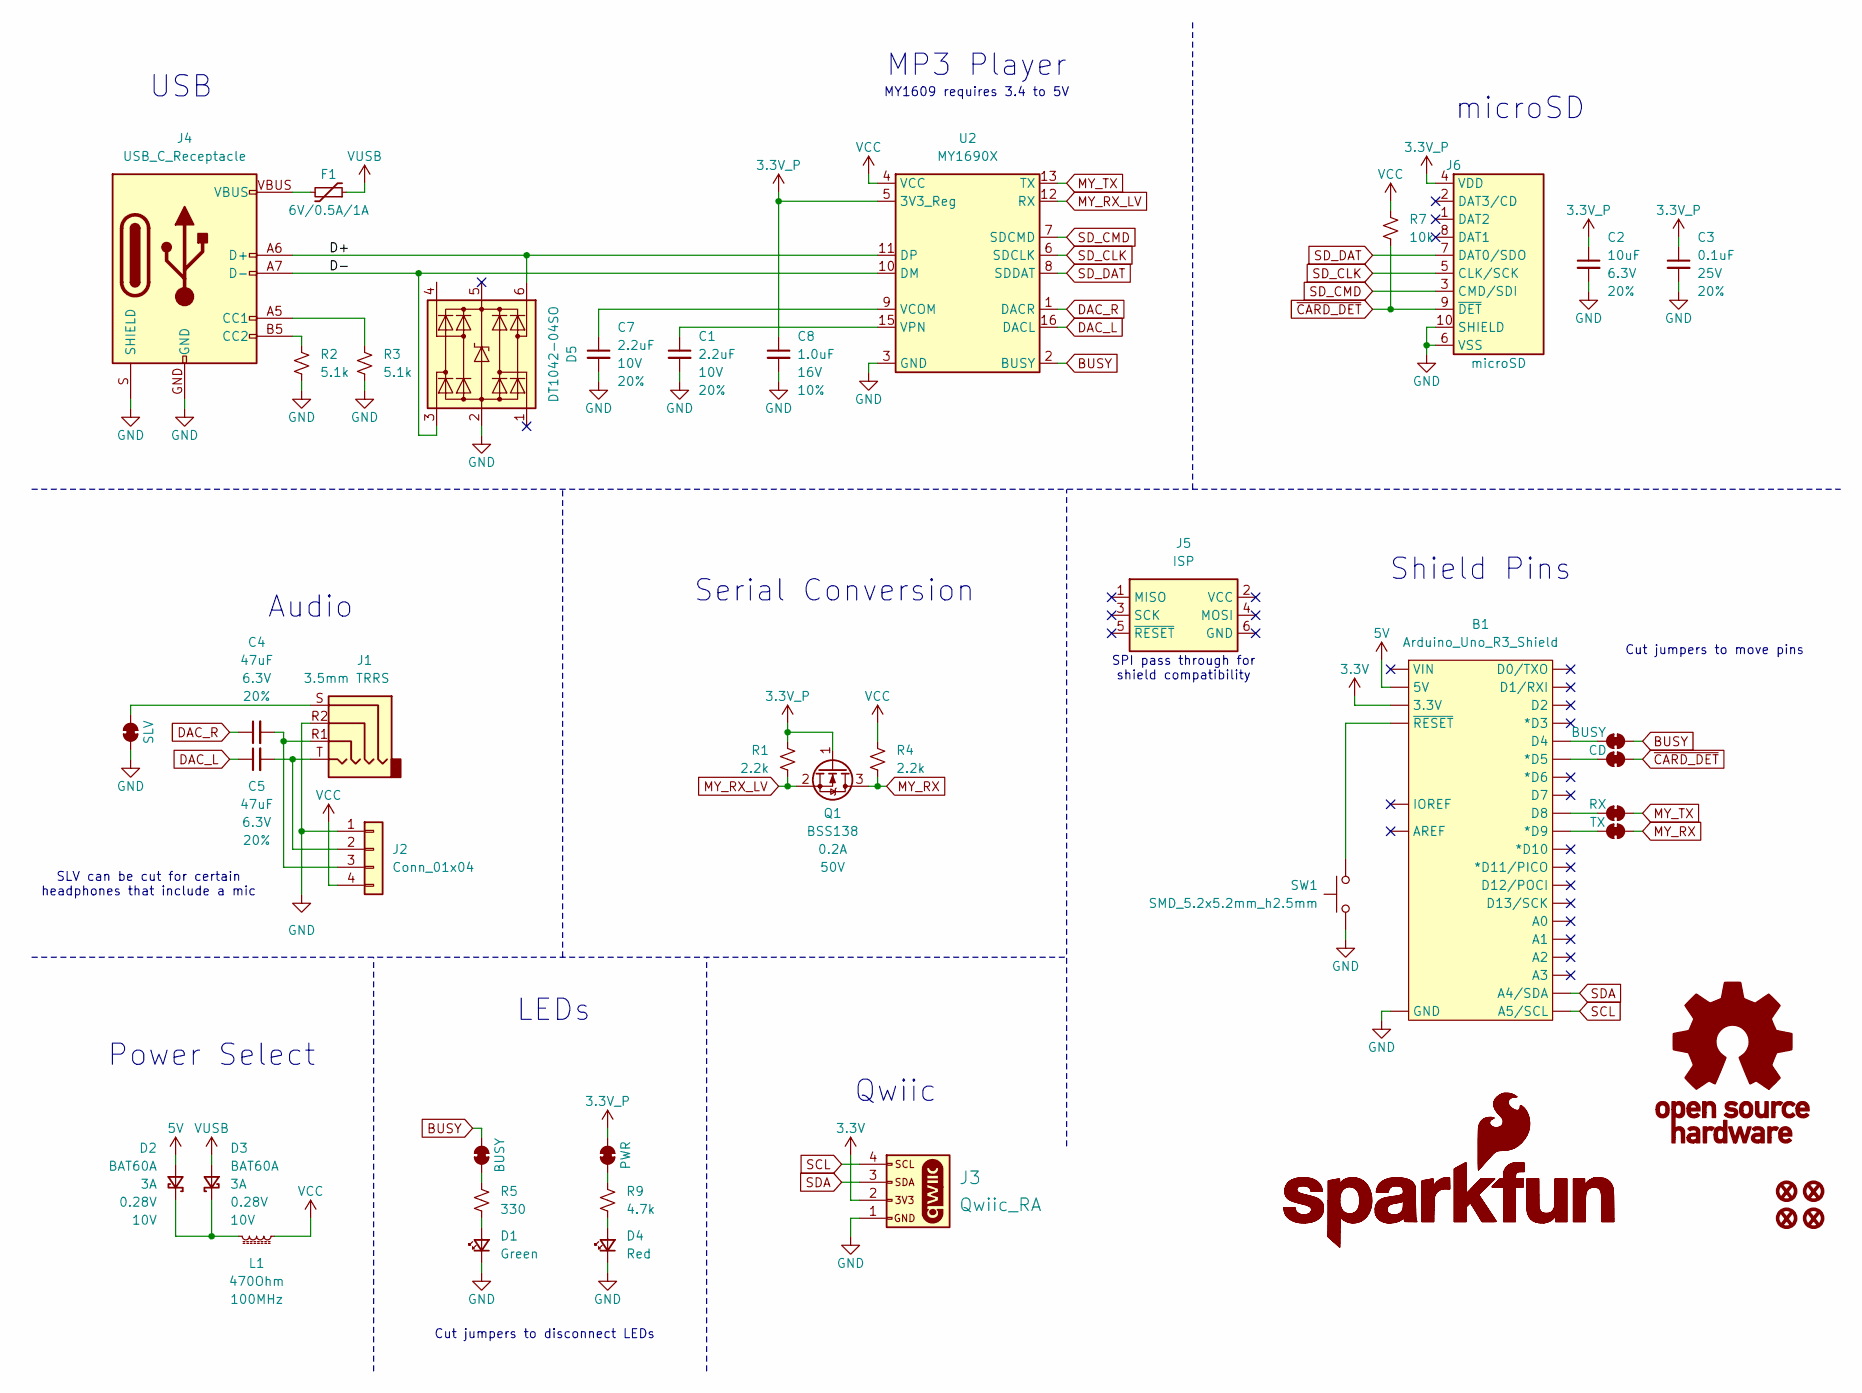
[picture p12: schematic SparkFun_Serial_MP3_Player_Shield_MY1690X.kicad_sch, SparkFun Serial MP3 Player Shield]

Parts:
B1: Arduino_Uno_R3_Shield; Uno_R3_Shield_NoLabels
C1, C7: 2.2uF; C_0603_1608Metric; Voltage 10V; Tolerance 20%
C2: 10uF; C_0603_1608Metric; Voltage 6.3V; Tolerance 20%
C3: 0.1uF; C_0603_1608Metric; Voltage 25V; Tolerance 20%
C4, C5: 47uF; C_0805_2012Metric; Voltage 6.3V; Tolerance 20%
C8: 1.0uF; C_0603_1608Metric; Voltage 16V; Tolerance 10%
D1: Green; LED_0603_1608Metric_Green
D2, D3: BAT60A; SOD-323
D4: Red; LED_0603_1608Metric_Red
D5: DT1042-04SO; SOT23-6
F1: 6V/0.5A/1A; 0805
FID1, FID2, FID3, FID4: Fiducial_0.5mm; Fiducial_0.5mm_Mask1mm
G1: OSHW_Logo; Creative_Commons_License
G3: SparkFun_Logo
G5: SparkFun_Logo; SparkFun_Logo_8mm
J1: 3.5mm TRRS; Audio_Jack_3.5mm_TRRS_SMD_RA
J2: Conn_01x04; 1x04
J3: Qwiic_RA; JST_SMD_1.0mm-4_Black
J4: USB_C_Receptacle; USB-C_16
J5: ISP; 2x03_NoSilk
J6: microSD; microSD_External_Pin
JP1: BUSY; Jumper_2_NC_Trace
JP2: PWR; Jumper_2_NC_Trace
JP3: CD; Jumper_2_PTH_SMD_Combo-NC
JP4: BUSY; Jumper_2_PTH_SMD_Combo-NC
JP5: RX; Jumper_2_PTH_SMD_Combo-NC
JP6: TX; Jumper_2_PTH_SMD_Combo-NC
JP7: SLV; Jumper_2_NC_Trace
L1: 470Ohm; C_0603_1608Metric
Q1: BSS138; SOT23-3
R1, R4: 2.2k; R_0603_1608Metric
R2, R3: 5.1k; R_0603_1608Metric
R5: 330; R_0603_1608Metric
R7: 10k; R_0603_1608Metric
R9: 4.7k; R_0603_1608Metric
SW1: SMD_5.2x5.2mm_h2.5mm; Push_SMD_5.2x5.2mm_h2.5mm
U2: MY1690X; SO-16

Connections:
3.3V: B1.3.3V, J3.2
3.3V_P: C2.1, C3.1, C8.1, J6.4 (VDD), JP2.2 (B), Q1.1 (G), R1.2, U2.5 (3V3_Reg)
5V: B1.5V, D2.2 (A)
/D+: D5.6 (I/O4), J4.A6 (D+), J4.B6 (D+), U2.11 (DP)
/D-: D5.3 (I/O2), J4.A7 (D-), J4.B7 (D-), U2.10 (DM)
BUSY: JP1.2 (B), JP4.2 (B), U2.2 (BUSY)
DAC_L: C5.1, U2.16 (DACL)
DAC_R: C4.1, U2.1 (DACR)
GND: B1.GND, C1.2, C2.2, C3.2, C7.2, C8.2, D1.1 (K), D4.1 (K), D5.2 (GND), J1.R2, J2.1, J3.1, J4.GND, J4.S (SHIELD), J6.6 (VSS), J6.10 (SHIELD), JP7.1 (A), R2.2, R3.1, SW1.1, U2.3 (GND), U2.14 (GND)
MY_RX: JP6.2 (B), Q1.3 (D), R4.1
MY_RX_LV: Q1.2 (S), R1.1, U2.12 (RX)
MY_TX: JP5.2 (B), U2.13 (TX)
unnamed: B1.D5 (*D5), JP3.1 (A)
unnamed: B1.D9 (*D9), JP6.1 (A)
unnamed: B1.~{RESET}, SW1.2
unnamed: D1.2 (A), R5.1
unnamed: D2.1 (K), D3.1 (K), L1.2
unnamed: D4.2 (A), R9.1
unnamed: F1.2, J4.VBUS
unnamed: C5.2, J1.T, J2.2
unnamed: C4.2, J1.R1, J2.3
unnamed: J4.A5 (CC1), R3.2
unnamed: J4.B5 (CC2), R2.1
unnamed: JP1.1 (A), R5.2
unnamed: JP2.1 (A), R9.2
unnamed: B1.D4, JP4.1 (A)
unnamed: B1.D8, JP5.1 (A)
unnamed: J1.S, JP7.2 (B)
unnamed: C7.1, U2.9 (VCOM)
unnamed: C1.1, U2.15 (VPN)
SCL: B1.A5/SCL, J3.4
SDA: B1.A4/SDA, J3.3
SD_CLK: J6.5 (CLK/SCK), U2.6 (SDCLK)
SD_CMD: J6.3 (CMD/SDI), U2.7 (SDCMD)
SD_DAT: J6.7 (DAT0/SDO), U2.8 (SDDAT)
VCC: J2.4, L1.1, R4.2, R7.2, U2.4 (VCC)
VUSB: D3.2 (A), F1.1
~CARD_DET: J6.9 (~DET), JP3.2 (B), R7.1

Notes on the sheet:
Cut jumpers to disconnect LEDs
MY1609 requires 3.4 to 5V
Serial Conversion
Cut jumpers to move pins
Audio
USB
microSD
SPI pass through for shield compatibility
SLV can be cut for certain headphones that include a mic
MP3 Player
Qwiic
Power Select
Shield Pins
LEDs

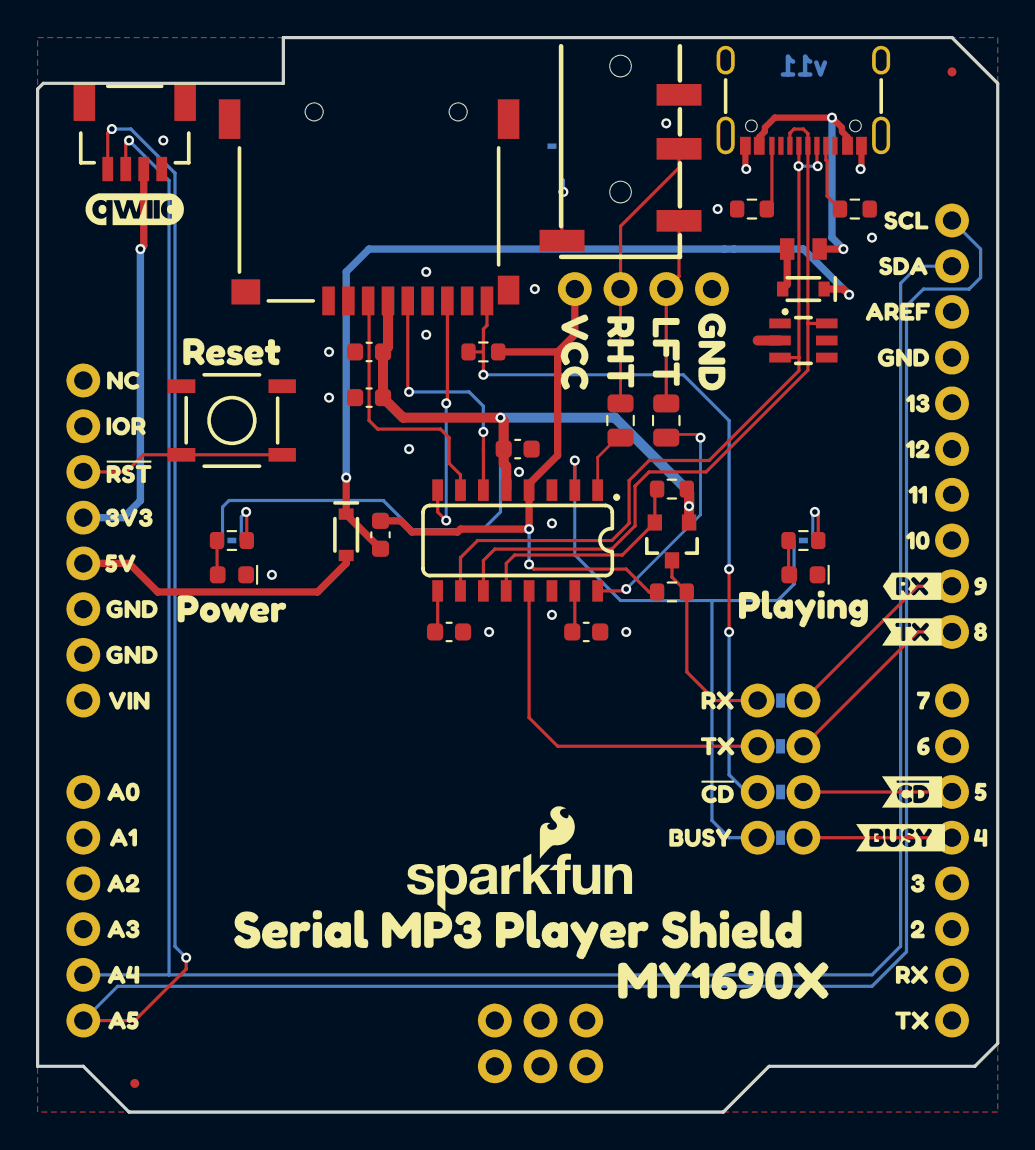
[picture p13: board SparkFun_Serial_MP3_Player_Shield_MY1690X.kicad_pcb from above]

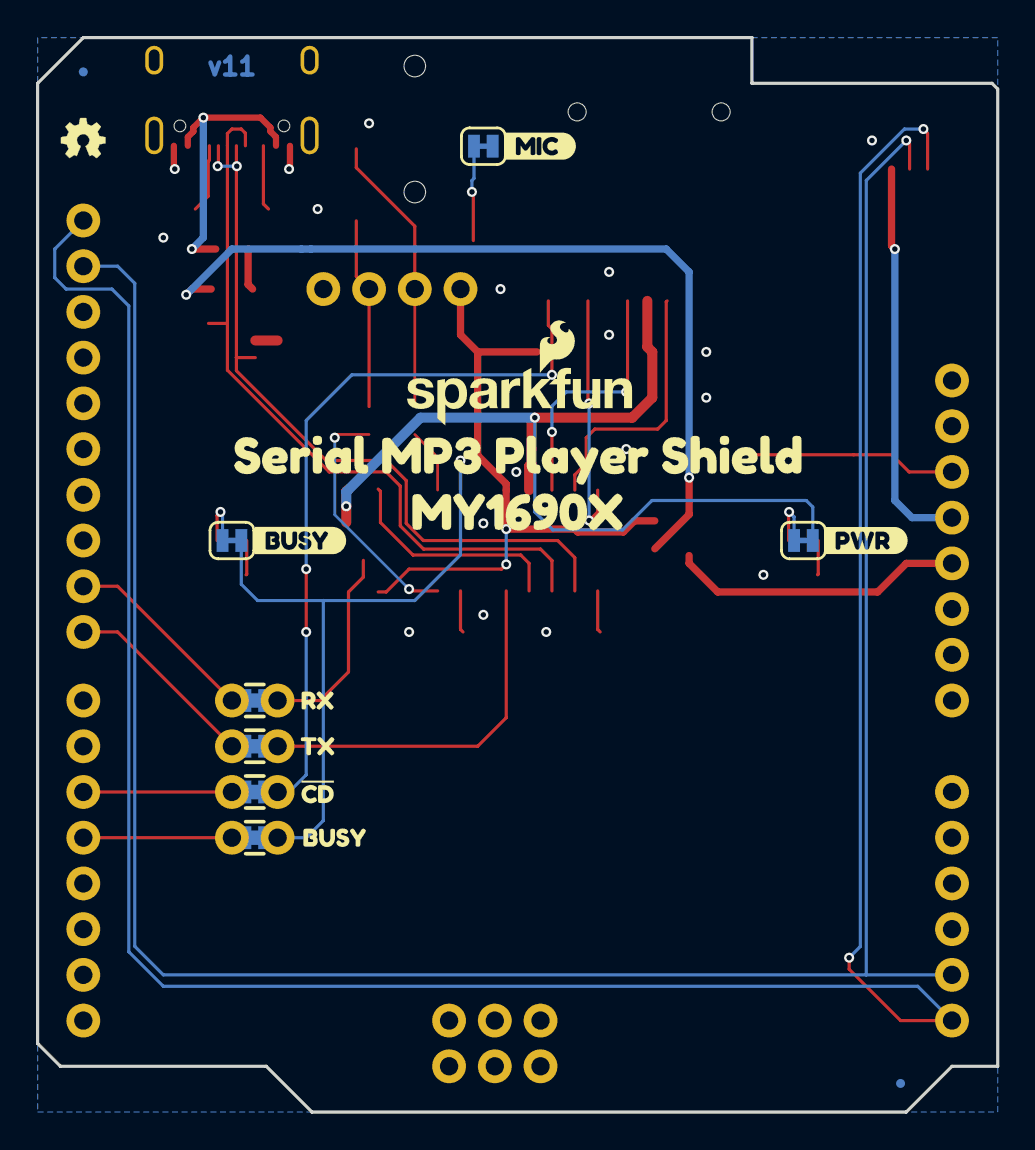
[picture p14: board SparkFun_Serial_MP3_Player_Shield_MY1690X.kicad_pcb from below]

Board: 2 copper layers, 53.3 x 59.7 mm, 102 parts (19 on the bottom side), 38 nets.

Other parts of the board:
Ref**: Val**; OSHW_Logo_2.5mm
kibuzzard-67A3E997, kibuzzard-67A3E997#2: G***; kibuzzard-67A3E997
kibuzzard-673AC551: G***; kibuzzard-673AC551
kibuzzard-673EA3A1: G***; kibuzzard-673EA3A1
kibuzzard-673EA43C: G***; kibuzzard-673EA43C
kibuzzard-673EA442: G***; kibuzzard-673EA442
kibuzzard-673EA447: G***; kibuzzard-673EA447
kibuzzard-673EA691: G***; kibuzzard-673EA691
kibuzzard-673EAACD, kibuzzard-673EAACD#2: G***; kibuzzard-673EAACD
kibuzzard-673EAE7C: G***; kibuzzard-673EAE7C
kibuzzard-673EAE8B: G***; kibuzzard-673EAE8B
kibuzzard-673EAE53: G***; kibuzzard-673EAE53
kibuzzard-673EAE60: G***; kibuzzard-673EAE60
kibuzzard-673EAEA7: G***; kibuzzard-673EAEA7
kibuzzard-673EAEB6: G***; kibuzzard-673EAEB6
kibuzzard-673EAEBB: G***; kibuzzard-673EAEBB
kibuzzard-673EAEC1: G***; kibuzzard-673EAEC1
kibuzzard-673EAEC8: G***; kibuzzard-673EAEC8
kibuzzard-673EAED1: G***; kibuzzard-673EAED1
kibuzzard-673EAEDE: G***; kibuzzard-673EAEDE
kibuzzard-673EAEE5: G***; kibuzzard-673EAEE5
kibuzzard-673EAF2D: G***; kibuzzard-673EAF2D
kibuzzard-673EAF5F: G***; kibuzzard-673EAF5F
kibuzzard-673EAF7B: G***; kibuzzard-673EAF7B
kibuzzard-673EAF7F: G***; kibuzzard-673EAF7F
kibuzzard-673EAF11: G***; kibuzzard-673EAF11
kibuzzard-673EAF23: G***; kibuzzard-673EAF23
kibuzzard-673EAF28: G***; kibuzzard-673EAF28
kibuzzard-673EAF33: G***; kibuzzard-673EAF33
kibuzzard-673EAF38: G***; kibuzzard-673EAF38
kibuzzard-673EAF45: G***; kibuzzard-673EAF45
kibuzzard-673EAF59: G***; kibuzzard-673EAF59
kibuzzard-673EAF71: G***; kibuzzard-673EAF71
kibuzzard-673EAF76: G***; kibuzzard-673EAF76
kibuzzard-673EAF83: G***; kibuzzard-673EAF83
kibuzzard-678AC9A2: G***; kibuzzard-678AC9A2
kibuzzard-678ACA35: G***; kibuzzard-678ACA35
kibuzzard-679D21EC: G***; kibuzzard-679D21EC
kibuzzard-679D21F4: G***; kibuzzard-679D21F4
kibuzzard-679D21F8: G***; kibuzzard-679D21F8
kibuzzard-679D21FD: G***; kibuzzard-679D21FD
kibuzzard-679D221C: G***; kibuzzard-679D221C
kibuzzard-679D222D: G***; kibuzzard-679D222D
kibuzzard-679D2133: G***; kibuzzard-679D2133
kibuzzard-679D2139: G***; kibuzzard-679D2139
kibuzzard-679D2221: G***; kibuzzard-679D2221
kibuzzard-679D2231: G***; kibuzzard-679D2231
kibuzzard-6792AB76: G***; kibuzzard-6792AB76
kibuzzard-6792AB99: G***; kibuzzard-6792AB99
kibuzzard-6792ACFA, kibuzzard-6792ACFA#2: G***; kibuzzard-6792ACFA
kibuzzard-6792ACFE, kibuzzard-6792ACFE#2: G***; kibuzzard-6792ACFE
kibuzzard-6792AD08, kibuzzard-6792AD08#2: G***; kibuzzard-6792AD08
kibuzzard-6792AD10, kibuzzard-6792AD10#2: G***; kibuzzard-6792AD10

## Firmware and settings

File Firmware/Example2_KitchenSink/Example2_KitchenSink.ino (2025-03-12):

/*
  Play an MP3 over software serial using the MY1690X MP3 IC
  By: Nathan Seidle
  SparkFun Electronics
  Date: December 10th, 2021
  License: MIT. See license file for more information but you can
  basically do whatever you want with this code.

  The MY1690 has a large number of features. This example presents the user
  with a serial menu to control the various aspects of the IC.

  Feel like supporting our work? Buy a board from SparkFun!
  https://www.sparkfun.com/products/28021

  Hardware Connections:
  MY1690 Pin -> Arduino Pin
  -------------------------------------
  TXO -> 8
  RXI -> 9
  3.3V -> 3.3V
  GND -> GND

  Don't forget to load some MP3s on your sdCard and plug it in too!
  Note: Track must be named 0001.mp3 to myMP3.playTrackNumber(1)
*/

#include "SparkFun_MY1690_MP3_Library.h" // Click here to get the library: http://librarymanager/All#SparkFun_MY1690

//For boards that support software serial, Arduino Uno, etc.
#include "SoftwareSerial.h"
SoftwareSerial serialMP3(8, 9); //format:(rx, tx) - RX on Arduino connected to TX on MY1690's, TX on Arduino connected to the MY1690's RX pin

//For boards that have multiple hardware serial ports, ESP32, etc.
//HardwareSerial serialMP3(1); //Create serial port on ESP32: pins are defined below

MY1690 myMP3;

void setup()
{
  Serial.begin(115200);
  Serial.println(F("MY1690 MP3 Example"));

  serialMP3.begin(9600); //The MY1690 expects serial communication at 9600bps

  //serialMP3.begin(9600, SERIAL_8N1, 26, 27); //Uncomment for ESP32: Assign pins RX, TX

  if (myMP3.begin(serialMP3) == false) // Beginning the MP3 player requires a serial port (either hardware or software)
  {
    Serial.println(F("Device not detected. Check wiring. Freezing."));
    while (1);
  }

  int songCount = myMP3.getSongCount();
  if (songCount == 0)
  {
    Serial.println(F("Oh no! No songs found. Make sure the SD card is inserted and there are MP3s on it. Freezing."));
    while (1);
  }

  Serial.print(F("Number of tracks on SD card: "));
  Serial.println(songCount);

  Serial.print(F("MY1690 Version: "));
  Serial.println(myMP3.getVersion());

  myMP3.play(); //Will play the lowest numbered song in the folder

  //It takes ~30ms for a track to start playing. If we check immediately, the track has not yet started.
  delay(50);

  int playStatus = myMP3.getPlayStatus();
  // 0 = stop, 1 = play, 2 = pause, 3 = fast forward, 4 = rewind

  Serial.print(F("playStatus: "));
  Serial.print(playStatus);
  if (playStatus == 1)
    Serial.println(F(" (playing)"));
  else if (playStatus == 0)
    Serial.println(F(" (stopped)"));

  myMP3.setVolume(5); //30 is loudest. 5 is comfortable with headphones. 0 is mute.

  Serial.print(F("Volume: "));
  Serial.println(myMP3.getVolume());

  myMP3.setPlayModeNoLoop();

  mainMenu();
}

void loop()
{
  if (Serial.available())
  {
    byte incoming = Serial.read();
    if (incoming == 's')
    {
      if(myMP3.stopPlaying() == true)
        Serial.println("Stop success");
      else
        Serial.println("Stop command failed");
    }
    else if (incoming == 'x')
    {
      if (myMP3.reset() == true)
        Serial.println("Reset success");
      else
        Serial.println("Reset command failed");
    }
    else if (incoming == 'a')
    {
      myMP3.volumeUp();
      Serial.print("Volume: ");
      Serial.println(myMP3.getVolume());
    }
    else if (incoming == 'z')
    {
      myMP3.volumeDown();
      Serial.print("Volume: ");
      Serial.println(myMP3.getVolume());
    }
    else if (incoming == 'f')
    {
      myMP3.fastForward();
    }
    else if (incoming == 'r')
    {
      myMP3.rewind();
    }
    else if (incoming == 'p')
    {
      myMP3.playPause();
    }
    else if (incoming == 'e')
    {
      int currentEQ = myMP3.getEQ();
      currentEQ++; //Go to next EQ. Device automatically wraps.

      myMP3.setEQ(currentEQ);

      currentEQ = myMP3.getEQ();
      Serial.print(F("Current EQ: "));
      Serial.println(currentEQ);
    }
    else if (incoming == 'm')
    {
      int currentMode = myMP3.getPlayMode();
      currentMode++; //Go to next mode.

      if(currentMode > 4) 
        currentMode = 0;

      myMP3.setPlayMode(currentMode);

      currentMode = myMP3.getPlayMode();
      Serial.print(F("Current Mode: "));
      Serial.println(currentMode);
    }
    else if (incoming == '<')
    {
      myMP3.playPrevious();
    }
    else if (incoming == '>')
    {
      myMP3.playNext();
    }
    else if (incoming == '#')
    {
      delay(20);
      while (Serial.available()) Serial.read();

      Serial.println(F("Track number to play: "));
      while (Serial.available() == 0) delay(1);
      int value = Serial.parseInt();
      
      // Note: Track must be named 0001.mp3 to myMP3.playTrackNumber(1)
      myMP3.playTrackNumber(value);
    }
    else if (incoming == 'c')
    {
      Serial.print(F("Current track: "));
      Serial.println(myMP3.getTrackNumber());
    }
    else if (incoming == 't')
    {
      Serial.print(F("Current track elapsed time (s): "));
      Serial.println(myMP3.getTrackElapsedTime());
    }
    else if (incoming == 'T')
    {
      Serial.print(F("Current track length (s): "));
      Serial.println(myMP3.getTrackTotalTime());
    }
    else if (incoming == '\r' || incoming == '\n')
    {
      //Ignore these
    }
    else
    {
      Serial.print(F("Unknown command: "));
      Serial.write(incoming);
      Serial.println();
      mainMenu();
    }
  }
}

void mainMenu()
{
  Serial.println();
  Serial.println(F("SparkFun MY1690 Menu:"));

  Serial.println(F("s) Stop play"));
  Serial.println(F("x) Reset IC"));
  Serial.println(F("a) Volume up"));
  Serial.println(F("z) Volume down"));
  Serial.println(F("f) Fast forward"));
  Serial.println(F("r) Reverse"));
  Serial.println(F("p) Play/Pause toggle"));
  Serial.println(F("e) Set EQ"));
  Serial.println(F("m) Set play mode"));
  Serial.println(F("<) Play previous"));
  Serial.println(F(">) Play next"));
  Serial.println(F("#) Play track number"));
  Serial.println(F("c) Current track number"));
  Serial.println(F("t) Track elapsed time"));
  Serial.println(F("T) Track total time"));
  Serial.println(F("Enter command:"));
}

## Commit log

2025-01-23 Add Busy LED, inline caps to TRRS, card detect, and power filtering.
    [SparkFun_Serial_MP3_Player_Shield_MY1690X.GBL, SparkFun_Serial_MP3_Player_Shield_MY1690X.GBO, SparkFun_Serial_MP3_Player_Shield_MY1690X.GBP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]
2025-01-27 Fix PROD ID on TRRS
    [SparkFun_Serial_MP3_Player_Shield_MY1690X.kicad_pcb, SparkFun_Serial_MP3_Player_Shield_MY1690X.kicad_sch]
2025-01-27 Add panel
    [SparkFun_Serial_MP3_Player_Shield_MY1690X.kicad_pcb]
2025-02-03 Post review updates.
    [SparkFun_Serial_MP3_Player_Shield_MY1690X.kicad_pcb, SparkFun_Serial_MP3_Player_Shield_MY1690X.kicad_sch]
2025-02-05 Add panel files
    [SparkFun_Serial_MP3_Player_Shield_MY1690X.kicad_pcb, SparkFun_Serial_MP3_Player_Shield_MY1690X.kicad_sch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]
2025-02-13 Updated top paste layer
    [SparkFun_Serial_MP3_Player_Shield_MY1690X_panelized.GTP]
2025-02-26 Add Board Dimensions to Measures Layer
    [SparkFun_Serial_MP3_Player_Shield_MY1690X.kicad_pcb]
2025-03-12 Change Playing resistor to 330
    [SparkFun_Serial_MP3_Player_Shield_MY1690X.kicad_pcb, SparkFun_Serial_MP3_Player_Shield_MY1690X.kicad_sch]
2025-04-07 Documentation
    Initial docs commit to add docs content & GH pages setup files/folders.
    [SparkFun_Serial_MP3_Player_Shield_MY1690X.kicad_pcb]

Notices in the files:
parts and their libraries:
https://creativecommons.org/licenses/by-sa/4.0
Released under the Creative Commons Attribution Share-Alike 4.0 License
